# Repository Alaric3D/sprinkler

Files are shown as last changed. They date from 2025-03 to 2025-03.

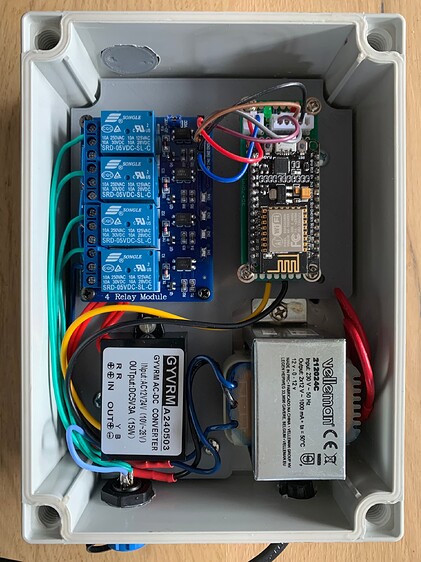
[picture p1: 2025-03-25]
hardware/Hardware-end-result.jpeg

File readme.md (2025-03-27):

# Sprinkler Automation with ESPHome / Home Assistant

## Overview
This project provides a comprehensive, DIY sprinkler automation solution using ESPHome and Home Assistant. It offers advanced irrigation control with features like zone management, scheduling, and smart home integration.

## Features
- **Multiple Zone Control**: Manage multiple irrigation zones independently
- **Flexible Scheduling**: 
  - Day-of-week scheduling
  - Time-of-day control
  - Custom duration for each zone
- **Smart Home Integration**
  - Home Assistant compatibility
  - Works offline
  - Rain delay feature
- **Open-Source**: Fully customizable and extendable

## Hardware Requirements
- ESP32 or ESP8266 microcontroller
- 8-channel relay module
- Power supply
- Valve solenoids
- (Waterproof) enclosure

## Software Requirements
- ESPHome
- Home Assistant
- MQTT (optional)

## Installation
1. Clone the repository
2. Configure `secrets.yaml`
3. Upload ESPHome configuration
4. Integrate with Home Assistant

## License
License v3.0 (GPL-3.0)

## Credits
- Original project concept by Alaric
- Home Assistant Community inspiration
```

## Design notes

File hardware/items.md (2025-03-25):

# Components
(for reference)
At Amazon.nl (April 10th 2023): total: € 78,78.

- 4 Channel relay board € 6,99
- NodeMCU (ESP8266 or ESP-32S) € 11,99
- Transformer (230VAC to 2x 12VAC) € 16,37
- DC Buck converter (12-24VAC to 5VDC) € 9,15
- 5 pin connector € 7,29
- Enclosure with transparent lid (180 x 130 x 90 mm) € 26,99
- NTC
- Control Cable (5x0,5mm) (to the valves in the garden)
- 24VAC electromagnetic valves

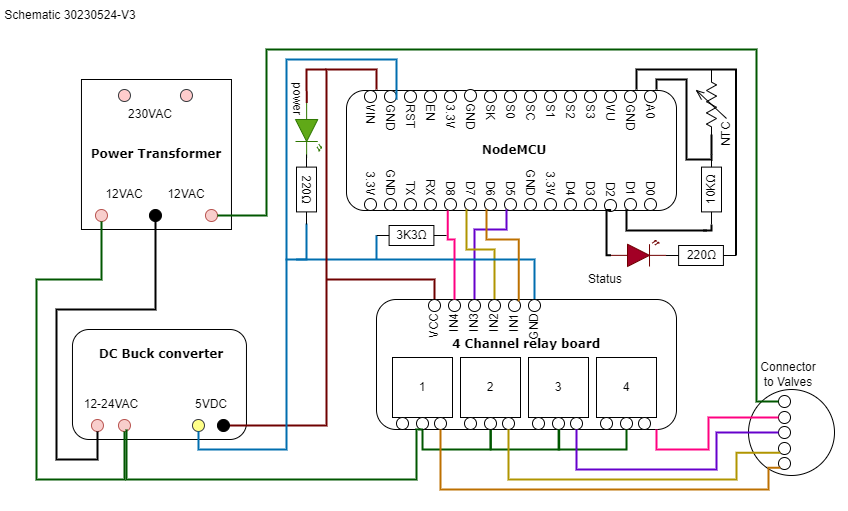
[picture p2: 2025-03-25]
hardware/schematic/schematic.png

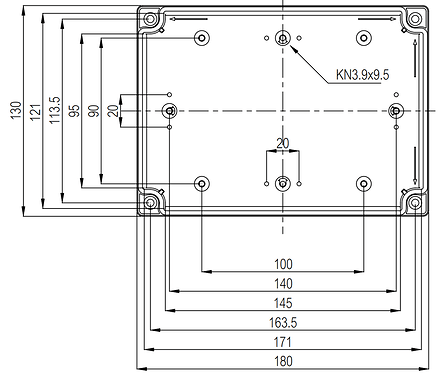
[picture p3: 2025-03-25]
hardware/Enclosure_dimensions.png

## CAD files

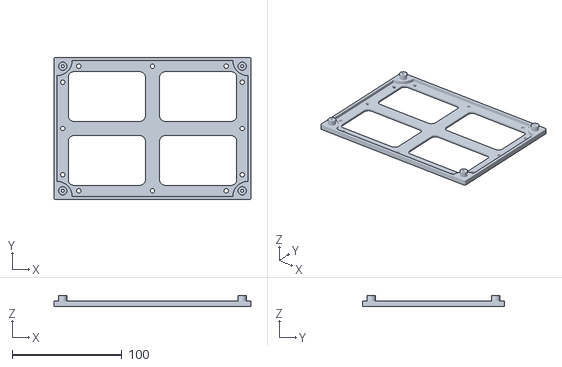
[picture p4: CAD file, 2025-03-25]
hardware/3d_models/wall_mount_part_2-2.stl
179.5 x 129.5 x 10.2

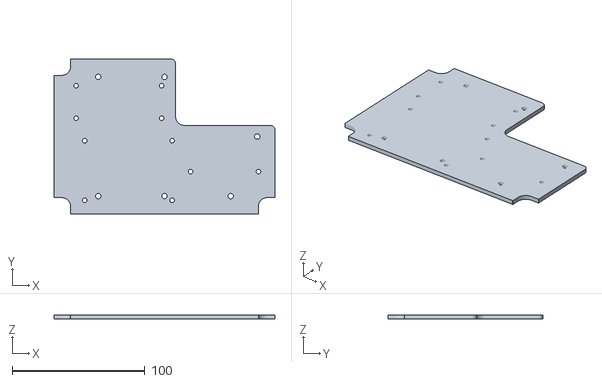
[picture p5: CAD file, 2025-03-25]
hardware/3d_models/Base_plate.stl
166.8 x 116.8 x 3.00

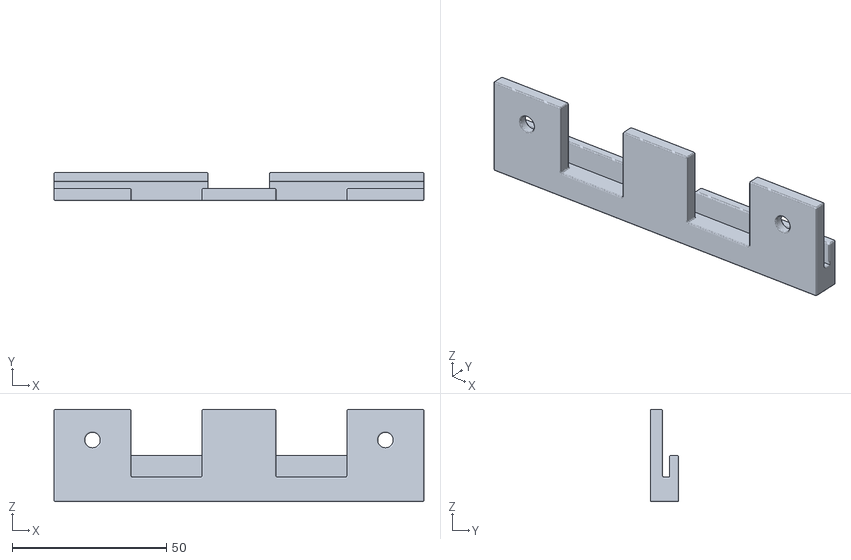
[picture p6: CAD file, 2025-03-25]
hardware/3d_models/Wall_mount_bracket.stl
120.0 x 9.20 x 30.0

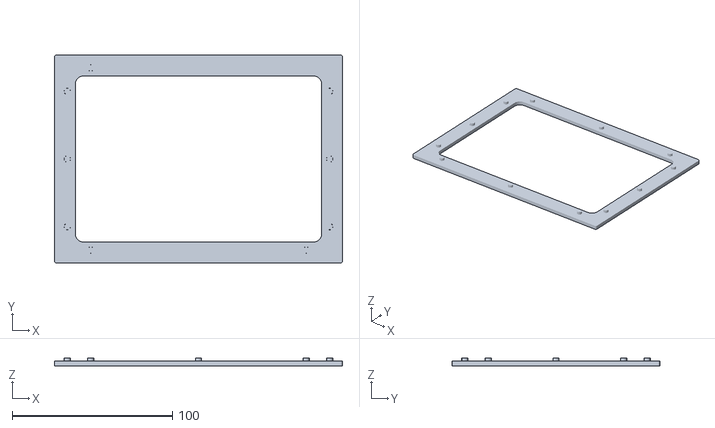
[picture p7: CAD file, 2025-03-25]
hardware/3d_models/wall_mount_part_1-2.stl
179.5 x 129.5 x 5.00

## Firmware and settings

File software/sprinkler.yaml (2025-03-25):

# Processing irrigation (board: nodemcuv2; framework: arduino; platform: platformio/espressif8266@3.2.0)
# --------------------------------------------------------------------------------
# HARDWARE: ESP8266 80MHz, 80KB RAM, 4MB Flash

# Based on ESPHome Sprinkler Controller - https://esphome.io/components/sprinkler.html
# Change Log
# 2023 01 XX
  # Initial version
  
# 2023 04 09 V03
  # fix run duration to seconds 
# 2023 04 22 V04
  # fix GPIO order to match relay 1- 4
  # added % at the lambda return for progress sensor return value
# 2023 04 25 V05
  # added nodemcu as sensor to display in HA ui
  # added includes for api key en ota password
# 2023 05 07 V06
  # added a NTC temp sensor to  watch the enclosure temperature
# 2023 05 10 V07
  # addjusted settings reference voltage to adjust to actual temp (default 3.3)
# 2023 06 06 V08
  # adjusted settings for valves corresponding to switches
  # added repeat function
# 2024 04 04 V09
  # Corrected the value of KEY ESPHOME_PROJECT_VERSION due to compiling error esphome v2024.3.1
  # initializer-string for 'char [30]' is too long
  # changed 2023 06 06 V08 to 20240404_V09
  # removed the text "Irrigation Controller.,"  
# 2025 03 12 V10
  # breaking change, configure platform explicitly

# Establish Substitutions
substitutions:
### Modify only the following 6 lines.
  zone_1_name: Drip Line A
  zone_2_name: Drip Lane B
  zone_3_name: Sprinkler A
  zone_4_name: Sprinkler B
  software_version: 20240404_V09
  sensor_update_frequency: 1s
  log_level: debug # Enable levels logging https://esphome.io/components/logger.html
  # none, error, warn, info, debug (default), verbose, very_verbose
##############################################
#  DO NOT CHANGE ANYTHING BELOW THIS LINE  ###
##############################################
  zone_1_valve_id: valve_0
  zone_2_valve_id: valve_1
  zone_3_valve_id: valve_2
  zone_4_valve_id: valve_3
  esphome_name: irrigation
  esphome_board: nodemcuv2
  esphome_comment: Four Valve Irrigation Controller
  esphome_project_name: jaya.Irrigation Controller
  esphome_project_version: $software_version
  devicename: irrigation_controller
  upper_devicename: "Irrigation Controller"
  uom: Min # this overrides the uom in sprinkler -> run_duration 


#Define Project Deatils and ESP Board Type
esphome:
  name: $esphome_name
  comment: $esphome_comment
  project:
    name: $esphome_project_name
    version: $esphome_project_version
  on_boot:
    priority: -100
    then:
      # Set default state for Valve Status
      - text_sensor.template.publish:
          id: valve_status
          state: "Idle"
      # Set multiplier to 60, convert seconds to minutes
      - sprinkler.set_multiplier:
          id: $devicename
          multiplier: 60

esp8266:
  board: $esphome_board

wifi:
  ssid: !secret wifi_ssid
  password: !secret wifi_password
# Enable fallback hotspot (captive portal) in case wifi connection fails
  ap:
    ssid: "$esphome_name Fallback Hotspot"
    password: !secret esphome_ap_password
  
logger:
  level: ${log_level}
  logs:
    text_sensor: WARN
  
ota:
  password: !secret esphome_ota_password

# Enable Web server.
web_server:
  port: 80

# Sync time with Home Assistant.
time:
  - platform: homeassistant
    id: homeassistant_time
    
###############################################
# Enable Home Assistant API
###############################################
api:
  encryption:
    key: !secret esphome_api_encrypt_key
  reboot_timeout: 0s

###############################################
# Binary Sensor.
###############################################
binary_sensor:
  - platform: homeassistant
    # prevent deep sleep - Needs further investigation on usefullness
    id: prevent_deep_sleep
    name: "$upper_devicename Prevent Deep Sleep"
    entity_id: input_boolean.prevent_deep_sleep  

###############################################
# Text sensors with general information.
###############################################
text_sensor:
  - platform: version # Expose ESPHome version as sensor.
    name: $esphome_name ESPHome Version
    hide_timestamp: false
  - platform: wifi_info
    ip_address:
      name: "$esphome_name IP"
    ssid:
      name: "$esphome_name SSID"
    bssid:
      name: "$esphome_name BSSID"
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
